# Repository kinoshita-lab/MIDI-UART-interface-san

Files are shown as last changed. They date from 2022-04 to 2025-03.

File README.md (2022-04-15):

# MIDI-UART interface-san Kit

MIDI UART interface-san is a handy interface PCB for MIDI and microcontrollers with commonly used basic circuit when you start developping  MIDI-related  MCU project, e.g. TRS jacks for MIDI I/O, optocouplers, digital buffers, etc. It means by using this PCB, you do not have to repeat soldering/making a breadboard for these purpose anymore.

You can choose both 5V and 3.3V for power supply(can be selected jumper pins), to match the voltage of the MCU you want to use.

the_image | width=400

## Kit contents

- Pre-assembled circuit board
- 3.5mm TRS Jack connectors (J1, J2)
- 1x3P Pin Headers(J3, J4)
- 1x4P Pin Socket(CN1)
- Jumper pins(yellow) 2pcs.
- MIDI DIN <-> TRS(3.5mm) conversion cable(A type) 2pcs.

## How to assemble

Solder all of the jacks and connectors on the circuit board.
Please refer to the following image.
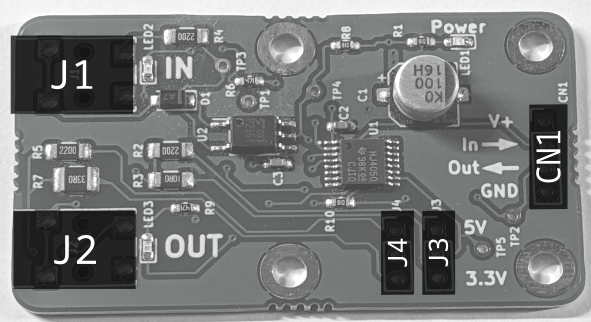
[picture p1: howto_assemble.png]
howto_assemble | width=400


## How to use

- Select operation voltage by shorting Jumper pins on J3, J4. By shorting above two pins for 5V, bottom two pins for 3.3V.
- Connect V+ and GND to the circuit board, breadboard, or something you want to use with this product.
- Connect `In->` to the MCU's MIDI Input.
- Connect `Out->` to the MCU's MIDI Output.

## Schematics, design data, etc

<https://github.com/kinoshita-lab/MIDI-UART-interface-san>

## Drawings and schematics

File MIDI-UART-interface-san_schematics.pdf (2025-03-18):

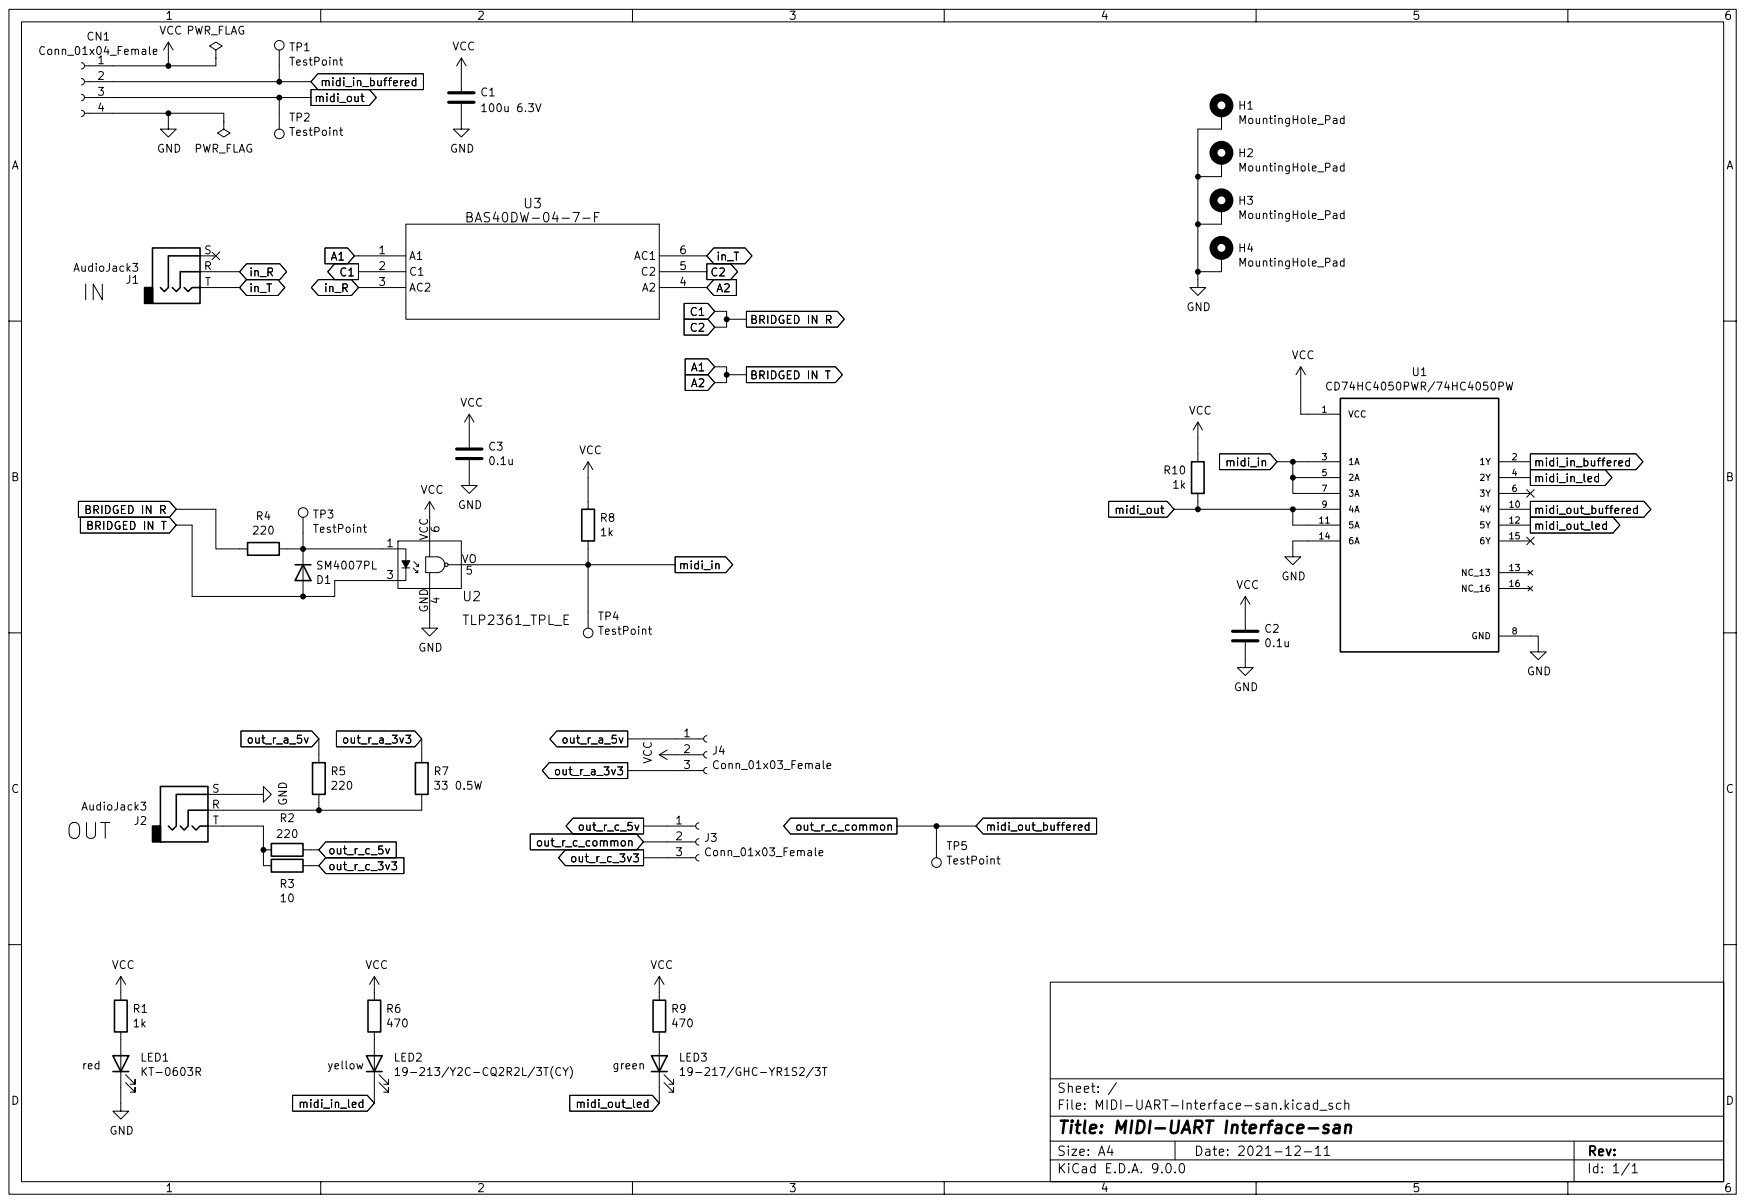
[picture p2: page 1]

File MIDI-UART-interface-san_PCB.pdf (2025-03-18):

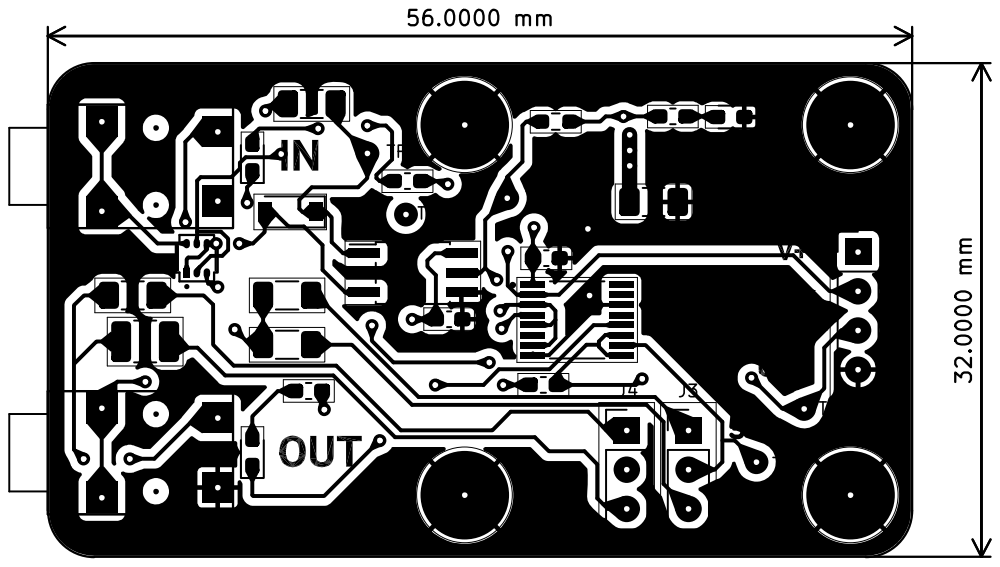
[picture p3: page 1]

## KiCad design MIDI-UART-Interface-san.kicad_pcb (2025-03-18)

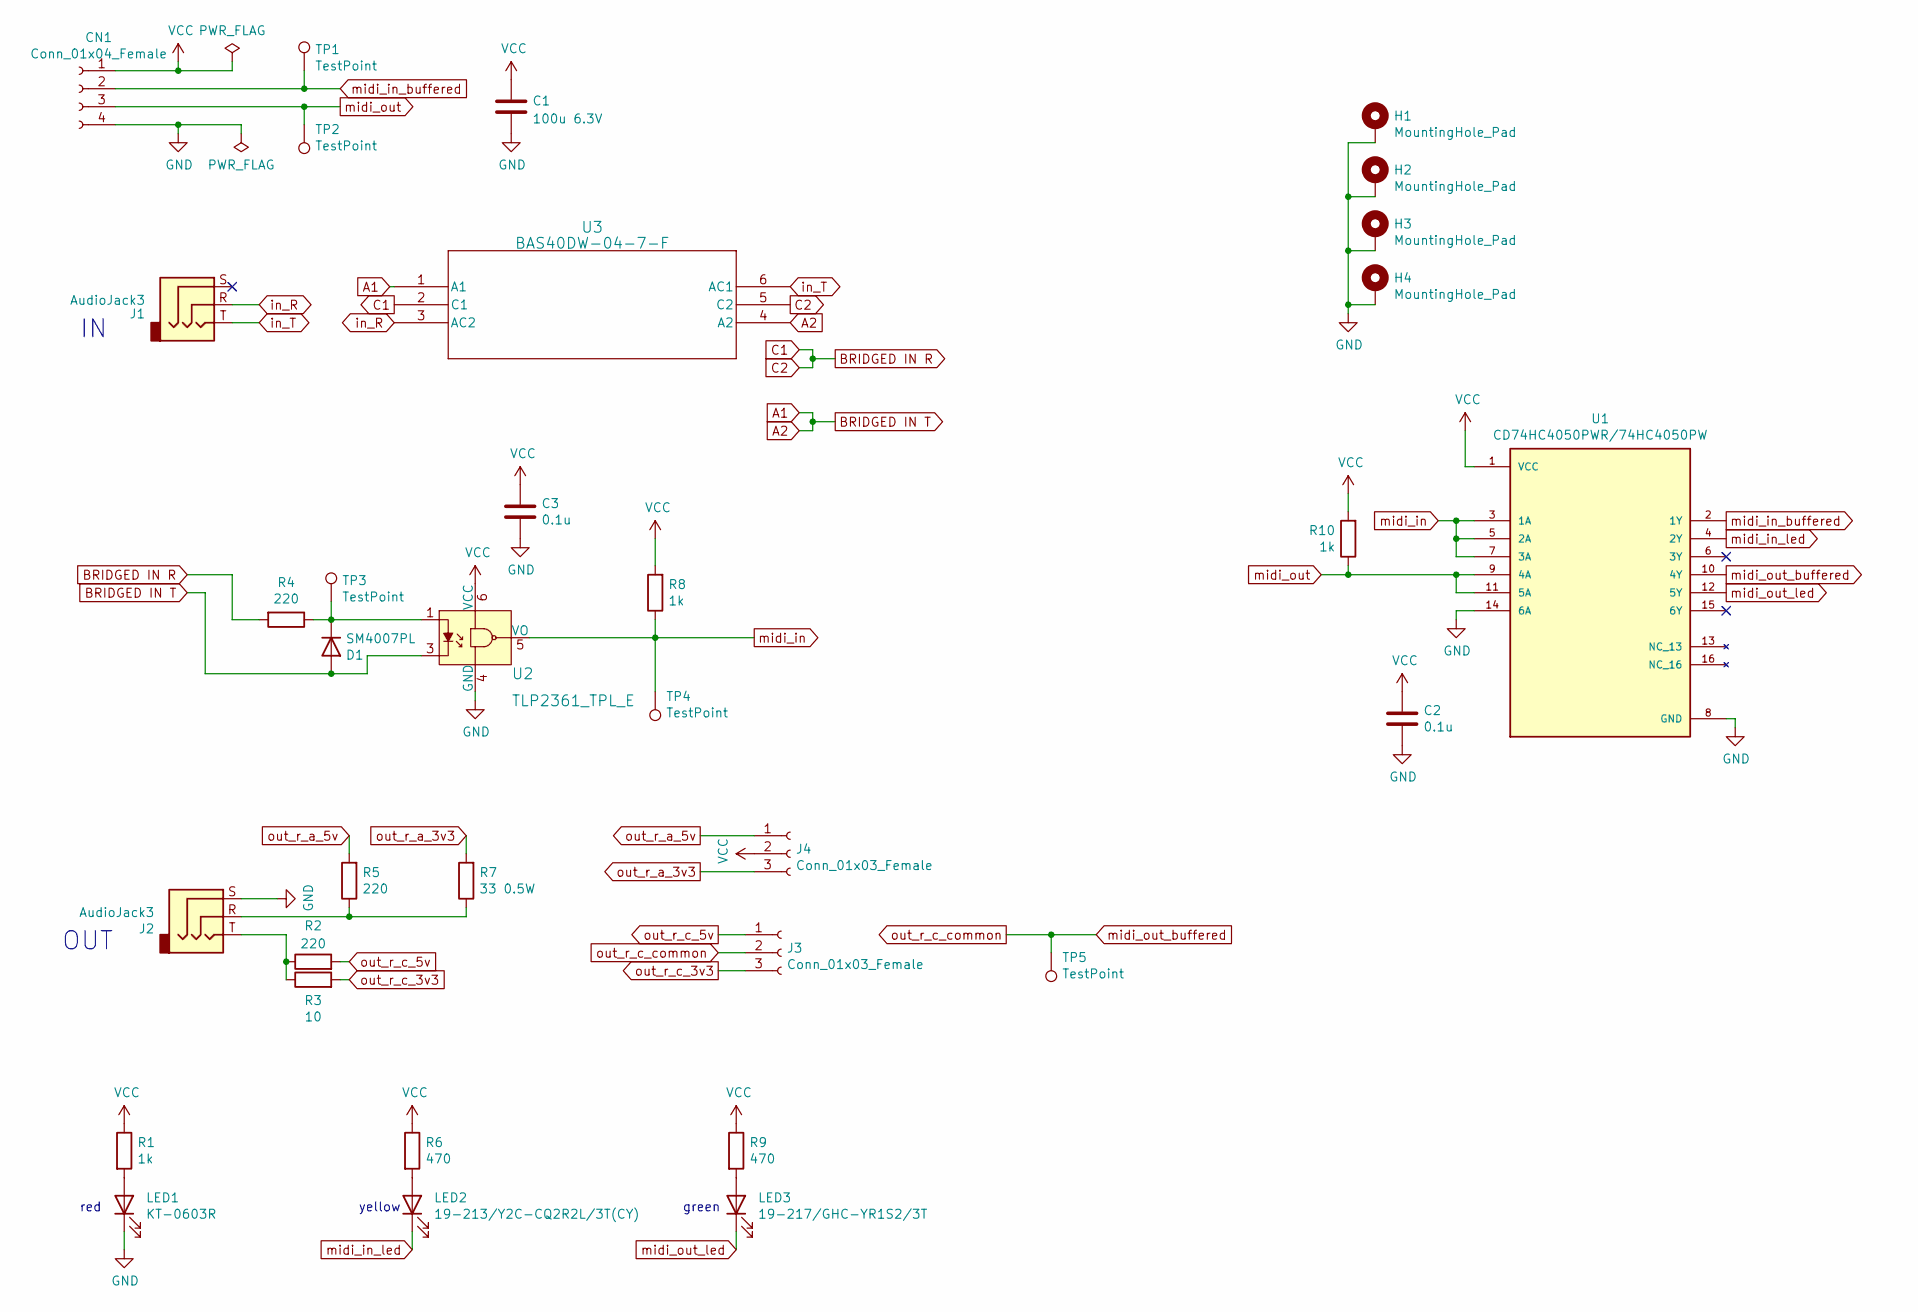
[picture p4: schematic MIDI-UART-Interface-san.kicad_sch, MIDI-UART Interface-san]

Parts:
C1: 100u 6.3V; C_1206_3216Metric_Pad1.33x1.80mm_HandSolder; LCSC C15008
C2, C3: 0.1u; C_0603_1608Metric_Pad1.08x0.95mm_HandSolder; LCSC C14663
CN1: Conn_01x04_Female; PinHeader_1x04_P2.54mm_Vertical; LCSC C124413
D1: SM4007PL; D_SOD-123; LCSC C64898
H1, H2, H3, H4: MountingHole_Pad; MountingHole_3.2mm_M3_ISO7380_Pad
J1, J2: AudioJack3; 3.5mm_Stereo_TRS_PJ-3210-4A_and_ST-005-G; LCSC C136686
J3, J4: Conn_01x03_Female; PinHeader_1x03_P2.54mm_Vertical; LCSC C49257
LED1: KT-0603R; LED_0603_1608Metric_Pad1.05x0.95mm_HandSolder; LCSC C965799
LED2: 19-213/Y2C-CQ2R2L/3T(CY); LED_0603_1608Metric_Pad1.05x0.95mm_HandSolder; LCSC C72038
LED3: 19-217/GHC-YR1S2/3T; LED_0603_1608Metric_Pad1.05x0.95mm_HandSolder; LCSC C72043
R1: 1k; R_0603_1608Metric_Pad1.05x0.95mm_HandSolder; LCSC C21190
R2, R4, R5: 220; R_1206_3216Metric_Pad1.30x1.75mm_HandSolder; LCSC C17957
R3: 10; R_1206_3216Metric_Pad1.30x1.75mm_HandSolder; LCSC C17903
R6, R9: 470; R_0603_1608Metric_Pad1.05x0.95mm_HandSolder; LCSC C21190
R7: 33 0.5W; R_1210_3225Metric_Pad1.30x2.65mm_HandSolder; LCSC C407192
R8: 1k; R_0603_1608Metric_Pad0.98x0.95mm_HandSolder; LCSC C22962
R10: 1k; R_0603_1608Metric_Pad1.05x0.95mm_HandSolder; LCSC C25804
TP1, TP2, TP3, TP4, TP5: TestPoint; TP_1PAD
U1: CD74HC4050PWR/74HC4050PW; SOP65P640X120-16N; PARTREV February 2005; LCSC C546991
U2: TLP2361_TPL_E; SO-5_4.4x3.6mm_P1.27mm; MPN TLP2361(TPL,E; Digi-Key_PN TLP2361(TPLECT-ND
U3: BAS40DW-04-7-F; SOT-363_DIO; LCSC C134364

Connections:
A1: D1.2 (A), U2.3, U3.1 (A1), U3.4 (A2)
BRIDGED IN R: R4.2, U3.2 (C1), U3.5 (C2)
GND: C1.2, C2.2, C3.2, CN1.4, H1.1, H2.1, H3.1, H4.1, J2.S, LED1.1 (K), U1.8 (GND), U1.14 (6A), U2.4 (GND)
unnamed: D1.1 (K), R4.1, TP3.1, U2.1
unnamed: J2.R, R5.1, R7.1
unnamed: J2.T, R2.1, R3.1
unnamed: LED1.2 (A), R1.2
unnamed: LED2.2 (A), R6.2
unnamed: LED3.2 (A), R9.2
VCC: C1.1, C2.1, C3.1, CN1.1, J4.2, R1.1, R6.1, R8.2, R9.1, R10.2, U1.1 (VCC), U2.6 (VCC)
in_R: J1.R, U3.3 (AC2)
in_T: J1.T, U3.6 (AC1)
midi_in: R8.1, TP4.1, U1.3 (1A), U1.5 (2A), U1.7 (3A), U2.5 (VO)
midi_in_buffered: CN1.2, TP1.1, U1.2 (1Y)
midi_in_led: LED2.1 (K), U1.4 (2Y)
midi_out: CN1.3, R10.1, TP2.1, U1.9 (4A), U1.11 (5A)
midi_out_buffered: J3.2, TP5.1, U1.10 (4Y)
midi_out_led: LED3.1 (K), U1.12 (5Y)
out_r_a_3v3: J4.3, R7.2
out_r_a_5v: J4.1, R5.2
out_r_c_3v3: J3.3, R3.2
out_r_c_5v: J3.1, R2.2

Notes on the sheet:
red
yellow
OUT
green

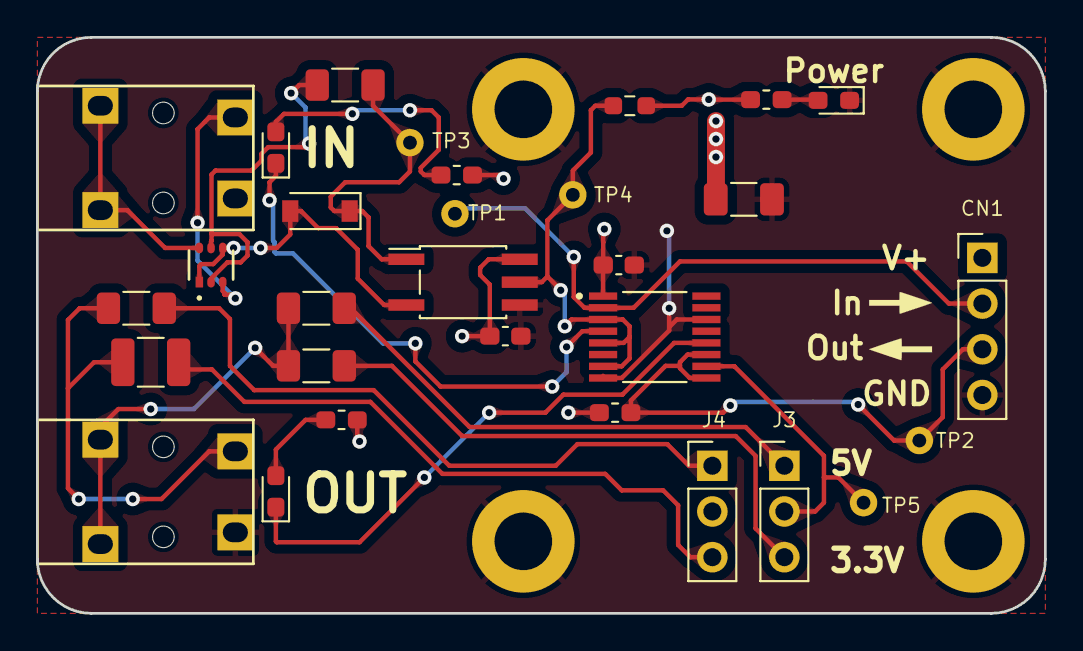
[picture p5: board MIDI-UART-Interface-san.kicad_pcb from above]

Board: 2 copper layers, 56.0 x 32.0 mm, 34 parts (0 on the bottom side), 22 nets.

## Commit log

2021-06-09 add kicad files from draft repository(w/ some renamings).
    [MIDI-UART-Interface-san.kicad_pcb, MIDI-UART-Interface-san.sch]
2021-06-09 replace pcb w/ renamed footprints.
    [MIDI-UART-Interface-san.kicad_pcb, MIDI-UART-Interface-san.sch]
2022-04-14 update to kicad 6.0.2
    [MIDI-UART-Interface-san.kicad_pcb, MIDI-UART-Interface-san.kicad_sch]
2024-06-22 Update to revision 2
    [MIDI-UART-Interface-san.kicad_pcb, MIDI-UART-Interface-san.kicad_sch]
2025-03-18 Revise to 2.1, KiCad 9.0
    [MIDI-UART-Interface-san.kicad_pcb, MIDI-UART-Interface-san.kicad_sch]
